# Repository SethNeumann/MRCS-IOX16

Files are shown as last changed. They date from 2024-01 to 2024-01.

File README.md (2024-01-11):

# REPO NAME: MRCS-IOX16

## License: Creative Commons Attribution-NonCommercial-ShareAlike

The IOX16 provides an 16 additonal lines of i/o for the cpNode using the MCP23017 chip.
IOX16 lines are configurable in as input or output in 8 bit (1 byte) increments.
Up to 128 lines of i/o may be added to a cpNode in any combination of IOX16s and IOX32s for a total of 144 lines of i/o.
Input and output voltages are limited to 5V.
Each output may sink up to 25 mA subject to a device limit of 160mA, if all lines are used as output use 10mA as a design limit.
Since the vast majority of outputs in a model railroad signaling system are used for driving LEDS, 10mA should be adequate.
If you need to work with higher voltages or currents, use the CSNK adapter in conjunction with the IOX16.
Pads for inserting limiting resistors are provided for each line.
Output pads are spaced at 0.100" to allow you maximum flexibility in configuring outputs.

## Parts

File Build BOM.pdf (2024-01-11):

## IOX16 Build BOM

Description | Ref | Qty | Supplier | Part No.
cpNode IOX16 PCB | PCB1 | 1 | MRCS | IOX16
MCP23017 | U1 | 1 | Digikey | MCP23017-E/SP-ND
Resistor Pack 2.2K 6 Pin | RP1 | 1 | Digikey | 4606X-1-222LF-ND
Capacitor .01uF 50v | C1 | 1 | Jameco | 25507
Diode Shottky 1N5819 | D1,D2 | 2 | Jameco | 177965
Male pin Hdr 1x2 2.54 mm | COM,5v | 0 | Jameco | 160882
Male pin Hdr 1x4 2.54 mm | I2C Hdr | 2 | Jameco | 160882
Male pin Hdr 1x16 2.54 mm | IO1,IO2 | 0 | Jameco | 160882
Male pin Hdr 3x2 2.54 mm | A0,A1,A2 | 1 | Jameco | 160882
DIP Socket 28 pin | MCP23017 | 1 | Jameco | 526248
2 pos Screw Terminal 2.54 mm | COM,5v | 2 | Electronics SalonGS019-2.54
8 pos Screw Terminal 2.54 mm | IO1,IO2 | 2 | Electronics SalonGS019-2.54
2 pos Screw Terminal 3.5 mm | J1 Ext 5v | 1 | Jameco | 2094506
SIP 16 machine tool round socketOption pads | | 2 | HSC | In store
Shorting Plug 0.100" | A0,A1,A2 | 0 | Jameco | 112432
4 wire I2C cable 6" | I2C Cable | 0 | Pololu

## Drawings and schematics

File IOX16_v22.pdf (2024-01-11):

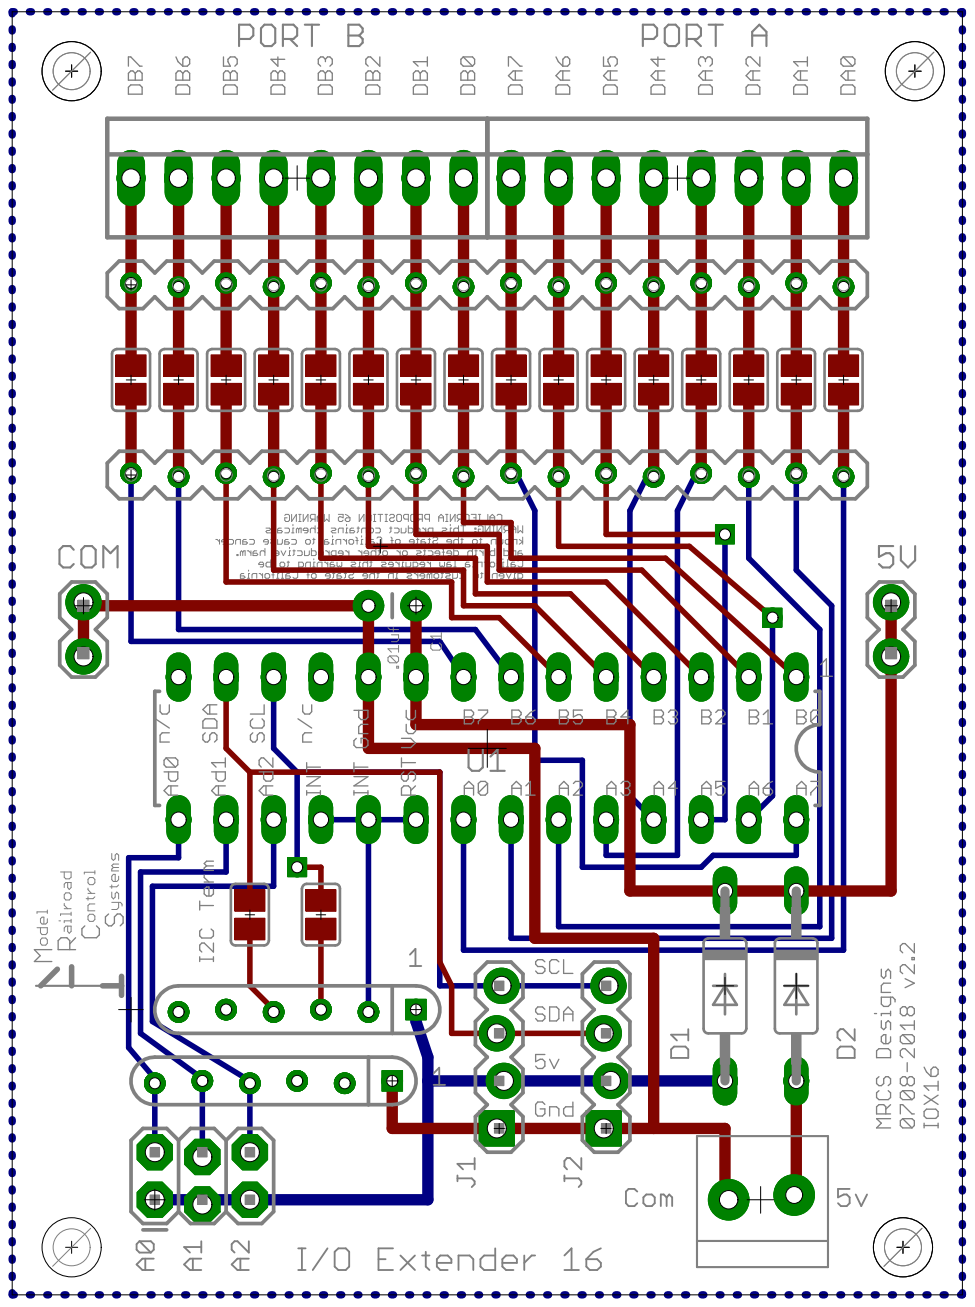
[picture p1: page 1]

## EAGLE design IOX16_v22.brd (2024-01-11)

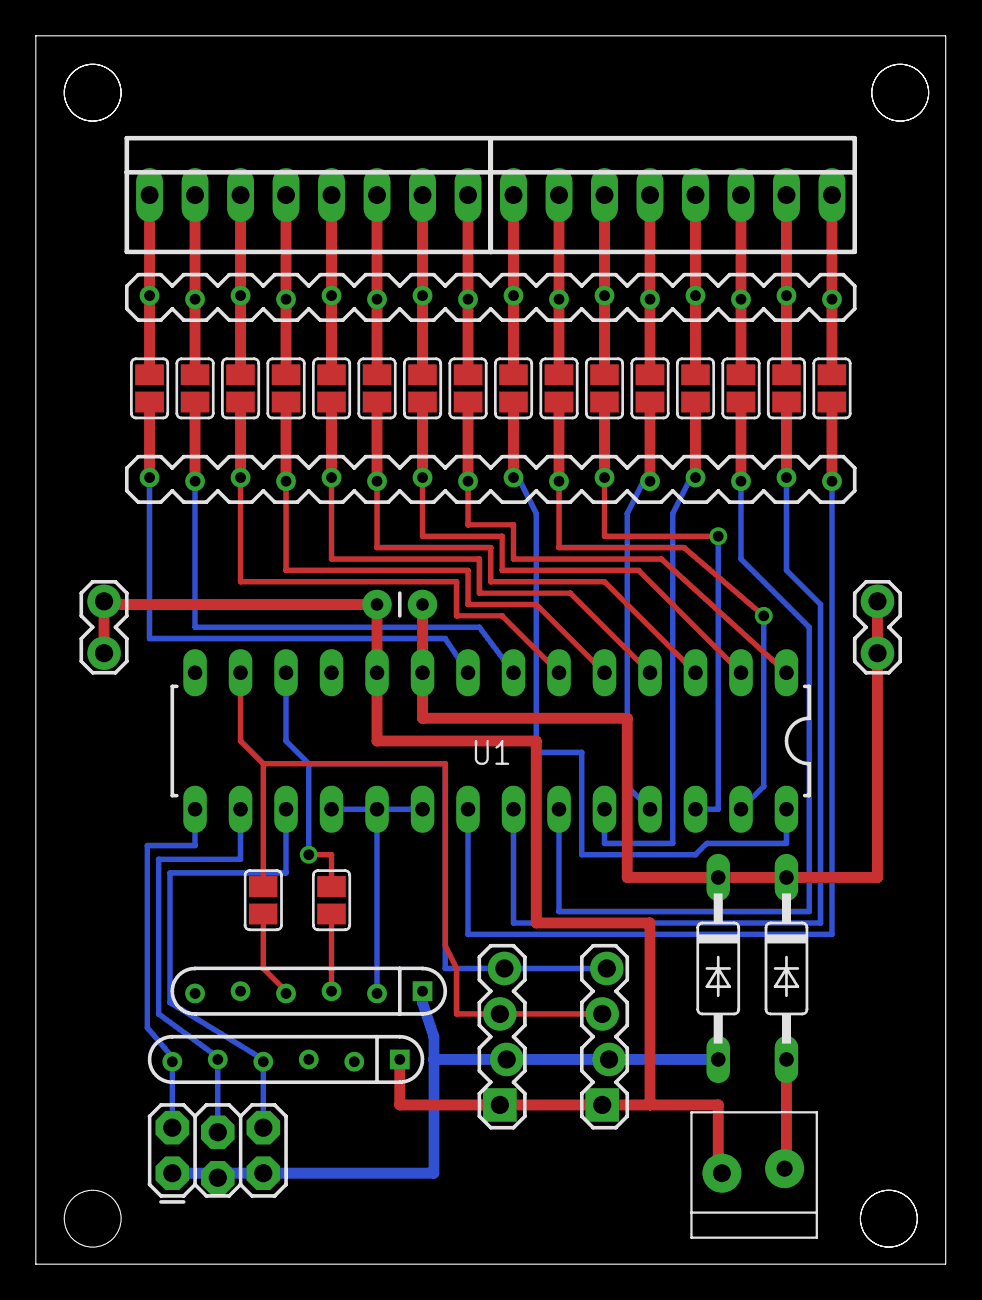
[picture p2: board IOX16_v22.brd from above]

Board: 2 copper layers, 50.8 x 68.6 mm, 43 parts (0 on the bottom side), 3 nets.

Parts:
5V: 1X02_LOCK
ADDR: 2X3_LOCK
C1: .01uf; CAP-PTH-SMALL
COM: 1X02_LOCK
D1: D1; C2992
D2: D2; C2992
E$1, E$3: 1X16_MACHINE-PIN-HEADER_LOCK.004
E$2, E$4: 1X04_LOCK
E$6, E$7, E$8, E$10, E$12, E$13, E$14: DRILL_0.1250
E$9: MRCSLOGOTOP
E$11: CA-PROP65WARNING
E$15: 3.5MMTERM
I2CT1, I2CT2: 2P-SMD-2X3.3
PORTA: 22-23-2081
PORTB: 22-23-2081
RP1, RP2: RPACK-SIP-PTH-5
SJ1, SJ2, SJ3, SJ4, SJ5, SJ6, SJ7, SJ8, SJ9, SJ10, SJ11, SJ12, SJ13, SJ14, SJ15, SJ16: 2P-SMD-2X3.3
U1: MCP23017; DIL28-3

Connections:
S$7: U1.18, U1.19, U1.20
S$18: ADDR.2, U1.15
S$52: C1.1, U1.9

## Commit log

2024-01-11 move existing files into Github
    [EagleTemplate-new.brd, EagleTemplate-new.sch, IOX16_v22.brd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]
2024-01-11 Delete cpNode_IOX16_BOM_20180708 v2.2.xlsx
    removed old BOM, new one coming
    [cpNode_IOX16_BOM_20180708 v2.2.xlsx]
2024-01-11 Create Build BOM.pdf
    Bill of Materials

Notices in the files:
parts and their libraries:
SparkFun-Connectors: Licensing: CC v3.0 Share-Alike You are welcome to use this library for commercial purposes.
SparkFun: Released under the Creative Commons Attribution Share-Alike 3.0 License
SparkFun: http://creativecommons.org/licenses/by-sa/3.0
